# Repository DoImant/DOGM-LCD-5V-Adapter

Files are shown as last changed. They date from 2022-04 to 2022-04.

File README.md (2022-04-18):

# 5V Adapter for the DOGMxxxxA Carrier Board.

This board is an adapter with which the 3.3V LCD-DOGMxxxx-A adapter board can also be operated with 5V (e.g. Arduino Nano/Uno).
Because the data flow is only unidirectional to the display, a 74LVC245A octal bus transceiver IC could be used as a level converter.

## Pictures
DOGM 5V to 3.3V Adapter. Front and back side.
Adapter Board. Back and front

Adapter board with LCD display on a breadboard.
Adapter board with LCD display on a breadboard.

Dogm LCD powerconsumption without backlight
Dogm LCD powerconsumption without backlight

Dogm LCD powerconsumtion with 25% backlight
Dogm LCD powerconsumtion with 25% backlight

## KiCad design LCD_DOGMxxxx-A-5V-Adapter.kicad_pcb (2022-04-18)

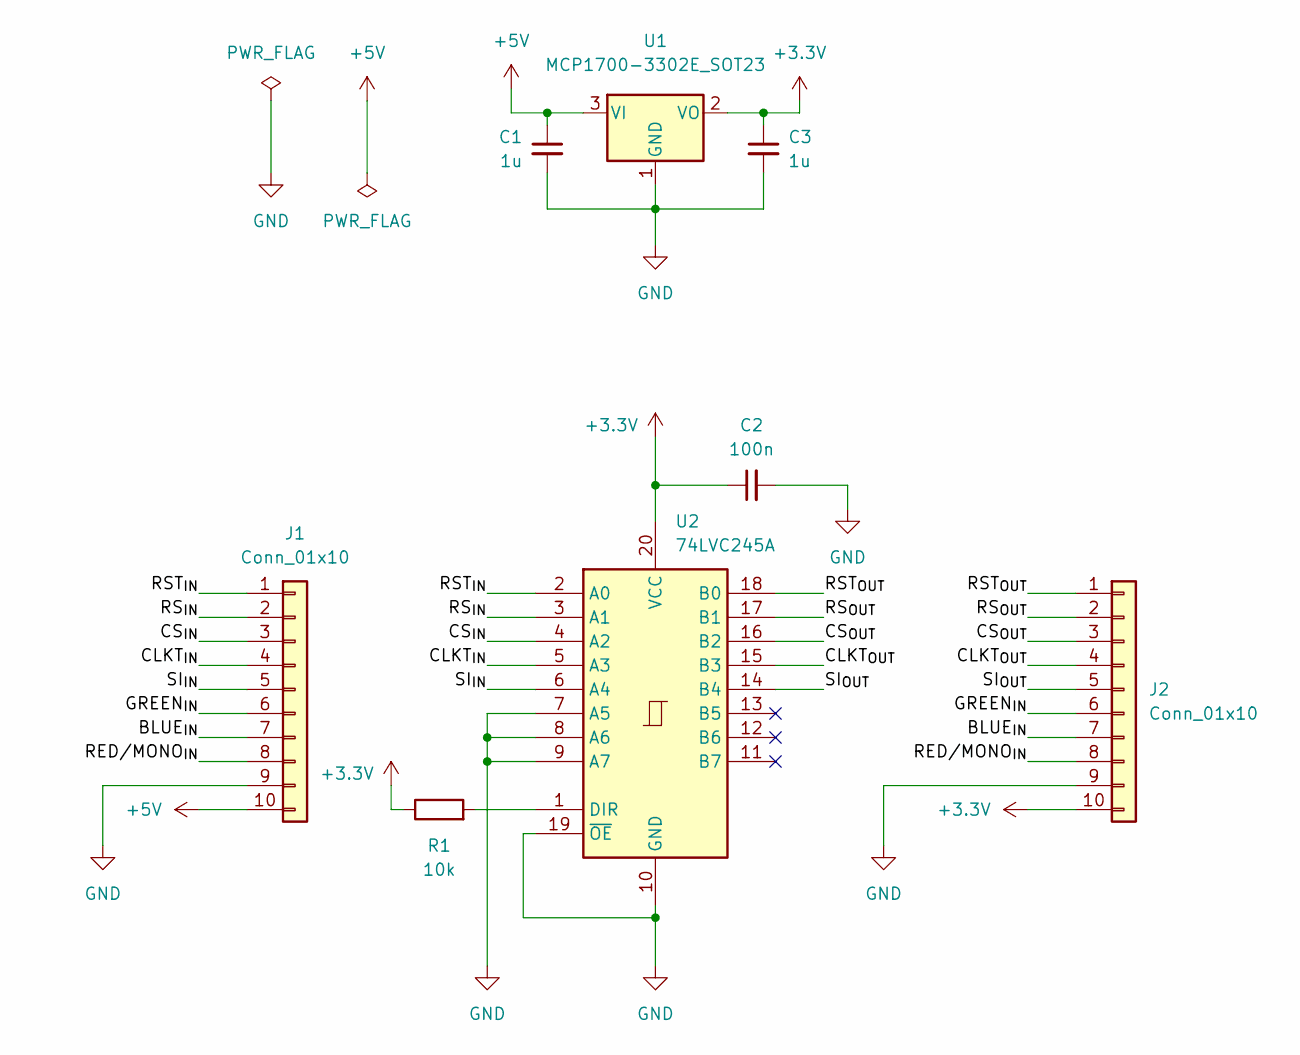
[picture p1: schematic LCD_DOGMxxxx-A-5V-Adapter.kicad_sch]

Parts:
C1, C3: 1u; C_1206_3216Metric_Pad1.33x1.80mm_HandSolder
C2: 100n; C_1206_3216Metric_Pad1.33x1.80mm_HandSolder
J1: Conn_01x10; PinHeader_1x10_P2.54mm_Vertical
J2: Conn_01x10; PinSocket_1x10_P2.54mm_Horizontal
R1: 10k; R_1206_3216Metric_Pad1.30x1.75mm_HandSolder
U1: MCP1700-3302E_SOT23; SOT-23
U2: 74LVC245A; TSSOP-20_4.4x6.5mm_P0.65mm

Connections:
+3V3: C2.1, C3.1, J2.10, R1.1, U1.2 (VO), U2.20 (VCC)
+5V: C1.1, J1.10, U1.3 (VI)
/BLUE_{IN}: J1.7, J2.7
/CLKT_{IN}: J1.4, U2.5 (A3)
/CLKT_{OUT}: J2.4, U2.15 (B3)
/CS_{IN}: J1.3, U2.4 (A2)
/CS_{OUT}: J2.3, U2.16 (B2)
/GREEN_{IN}: J1.6, J2.6
/RED/MONO_{IN}: J1.8, J2.8
/RST_{IN}: J1.1, U2.2 (A0)
/RST_{OUT}: J2.1, U2.18 (B0)
/RS_{IN}: J1.2, U2.3 (A1)
/RS_{OUT}: J2.2, U2.17 (B1)
/SI_{IN}: J1.5, U2.6 (A4)
/SI_{OUT}: J2.5, U2.14 (B4)
GND: C1.2, C2.2, C3.2, J1.9, J2.9, U1.1 (GND), U2.7 (A5), U2.8 (A6), U2.9 (A7), U2.10 (GND), U2.19 (~OE)
unnamed: R1.2, U2.1 (DIR)

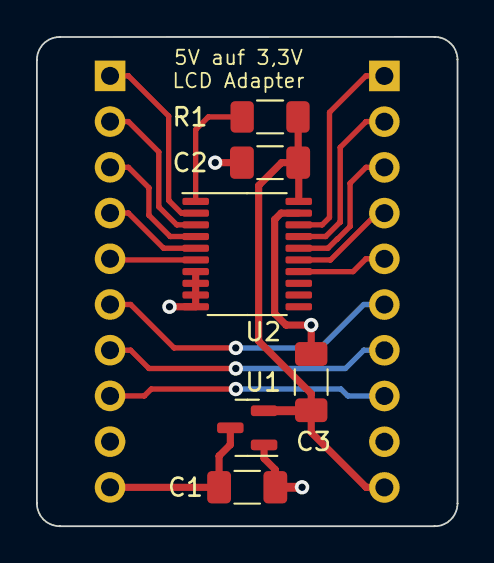
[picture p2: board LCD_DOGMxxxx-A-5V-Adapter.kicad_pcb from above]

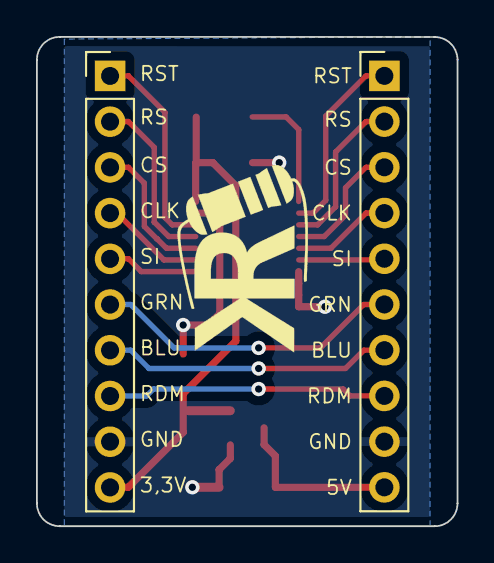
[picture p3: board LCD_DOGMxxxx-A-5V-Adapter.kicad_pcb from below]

Board: 2 copper layers, 23.4 x 27.2 mm, 8 parts (2 on the bottom side), 17 nets.
